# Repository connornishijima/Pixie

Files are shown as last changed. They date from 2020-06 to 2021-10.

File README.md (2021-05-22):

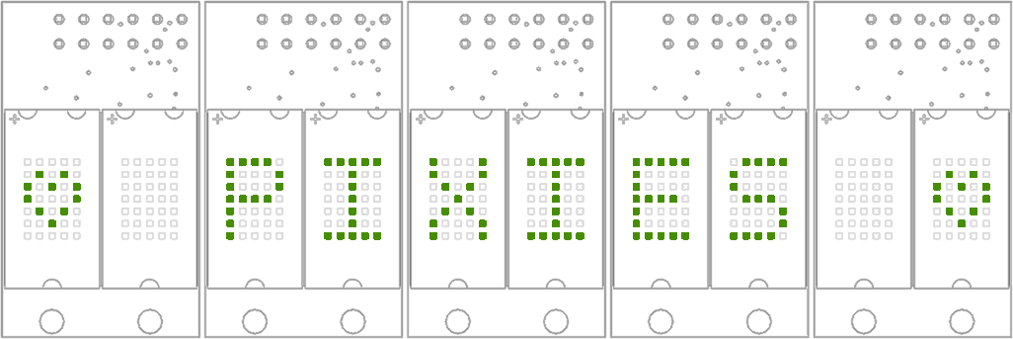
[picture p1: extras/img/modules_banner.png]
Pixie


----------
# Pixie for Arduino

https://www.tindie.com/products/connornishijima/pixie-chainable-dual-57-micro-led-displays/

**Pixies are chainable 5x7 microdot LED matrices great for showing... just about anything you can throw at them!**

- Dual 5x7 LED matrices
- 2.7V to 5.5V supply
- Fast bitmap control
- 7-bit global PWM (128 brightness levels)
- Over-temperature protection
- Resettable from controlling device
- Reprogrammable ATTINY45 microcontroller
- 5.1mm * 7.6mm matrix size (19.92 ppi)
- 20.6mm * 34.7mm package
- M2.5 mouting holes
- Controllable LED current (Pixie Pro)
- Parity bit error detection (Pixie Pro)

PIXIE
*Pixies mounted into a home-made case!*

# New to Pixies?

Thank you for your order! Try our **[Getting Started Guide](https://github.com/connornishijima/Pixie/blob/master/getting_started.md)** to get them wired up!

## Included in this repository:

**[PIXIE WEBSITE](https://connornishijima.github.io/Pixie/) *(Contains all documentation and tools in one spot)***

- Arduino Library Source Code
- Software Documentation
- Hardware Datasheet
- Pixie Icon Generator
- Raspberry Pi Python Driver
- PCB Gerbers

## Software Documentation

Documentation for the Pixie library is available in both the /examples directory for Arduino, and at the site below:

**[Library Documentation & Usage](https://connornishijima.github.io/Pixie/extras/documentation.html)**

We also have a **[Getting Started Guide](https://github.com/connornishijima/Pixie/blob/master/getting_started.md)** to help you get set up for the very first time!

## Hardware Documentation

Pixie has a comprehensive hardware datasheet (including internal firmware documentation and package dimensions for mounting) available here:

**[PIXIE DATASHEET](https://connornishijima.github.io/Pixie/extras/datasheet.html)**

This library also contains a Pixie EAGLE library (In "extras/hardware") for adding Pixies into your own PCB layouts!

----------
# Arduino Library Installation

**With Arduino Library Manager:** ***(Stable - RECOMMENDED)***

1. Open *Sketch > Include Library > Manage Libraries* in the Arduino IDE.
2. Search for "Pixie" by Connor Nishijima, and select the latest version.
3. Click the Install button and Arduino will prepare the library and examples for you!

**Manual Install:** (Hourly Builds)

1. Click "Clone or Download" above to get an "Pixie-master.zip" file.
2. Extract its contents to the libraries folder in your Arduino sketchbook. ("C:/Users/**YOUR_USERNAME**/Documents/Arduino/libraries" on Windows)
3. Rename the folder from "Pixie-master" to "Pixie".

----------
# Build Status


Pixie for Arduino is automatically tested with Travis CI against:
- ATmega328p (Uno)
- ATmega2560 (Mega)
- ATmega32u4 (Leonardo)
- ESP8266
- ESP32

*Currently untested are STM/Cortex or SAMD platforms such as the Teensy 3+ and Arduino MKR.*

Is it marked "Failing"? **No worries!** If you install Pixie using the Arduino Library Manager, you'll be getting the latest stable release. *This GitHub repo is under frequent changes, and some of these changes may be breaking at times.*

----------
# Contributing
Any advice or pull requests are welcome! *(This repository uses **snake_case**, not **camelCase**.)* :)

----------
# License and Credits
**Developed by Connor Nishijima (Copyright 2020)**

I work full-time as a Tindie seller providing income for my family. You are free to make your own Pixies with the infomation provided in this repository, but **please be ethical and *do not sell clones***. If you modify any information from this repository, and have used it to make improvements to my hardware design that you truly think makes your version superior to the original (and thus could compete in sales due to these advantages) then - at the very least - **please attribute** Lixie Labs LLC. if you sell them. (As required by the GPLv3 License below and included in the root of this repository.)

**Released under the [GPLv3 License](http://www.gnu.org/licenses/gpl-3.0.en.html).**

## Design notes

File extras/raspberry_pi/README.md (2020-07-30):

# Pixie Python driver for Raspberry Pi

This is a (mostly) complete port of version 1.2.2 of the Pixie Arduino library to a Python/SPI-based module for Raspberry Pi!

## Notable differences:

Since this is based on Hardware SPI, only the SPI pins can be used to drive the Pixies:

    PIXIE DAT = RPi MOSI
    PIXIE CLK = RPi SCLK
    (No Chip Select or MISO pins used)
    
- **pix.print()** is **pix.printout()** instead to avoid conflict with Python's **print()** function.
- The driver uses SPI at 20,000Hz by default, which can be increased or decreased in **pixie.py**
- **pixie.py** is the Pixie driver, (library equivalent) and must be in the same folder of any scripts importing it.
- This port contains all of the icons included with version 1.2.2, and newer ones may be added by request.
- Custom icons must be defined in brackets when given to a printing function. (Instead of *pix.write(127,127,127,127,127)* you'll need *pix.write(**[**127,127,127,127,127**]**)*
- There is a slightly longer-form way of fetching built-in icons. Instead of pix.write(PIX_HEART) use pix.write(pix.icons["PIX_HEART"])
- pix.flipped() (upside down display), pix.set_pix() and pix.draw_line() are not yet supported.

Other than that, usage is identical to the original library!

### SPI must be enabled using "sudo raspi-config" under "Interfacing Options" (reboot after changing)

#### SPI HOOKUP:
    -----------------+
                     |
     PIX_VCC     X   |
           X     X   |
           X     PIX_GND
           X     X   |
           X     X   |
           X     X   |
           X     X   |
           X     X   |
           X     X   |
     PIX_DAT     X   |
           X     X   |
     PIX_CLK     X   |
           X     X   |
           X     X   |
           X     X   |
           X     X   |
           X     X   |
           X     X   |
           X     X   |
           X     X   |
                     |

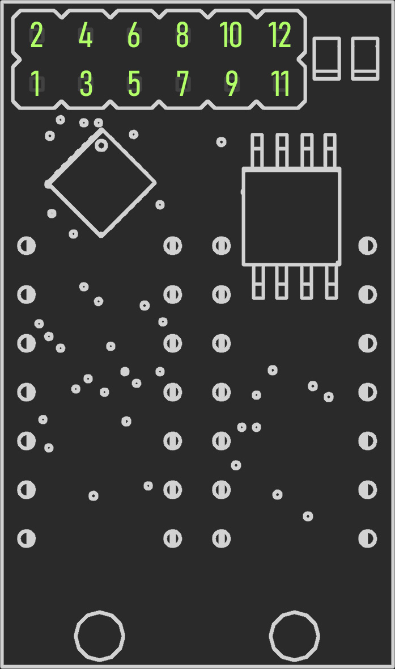
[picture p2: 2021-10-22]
extras/img/pinout.jpg

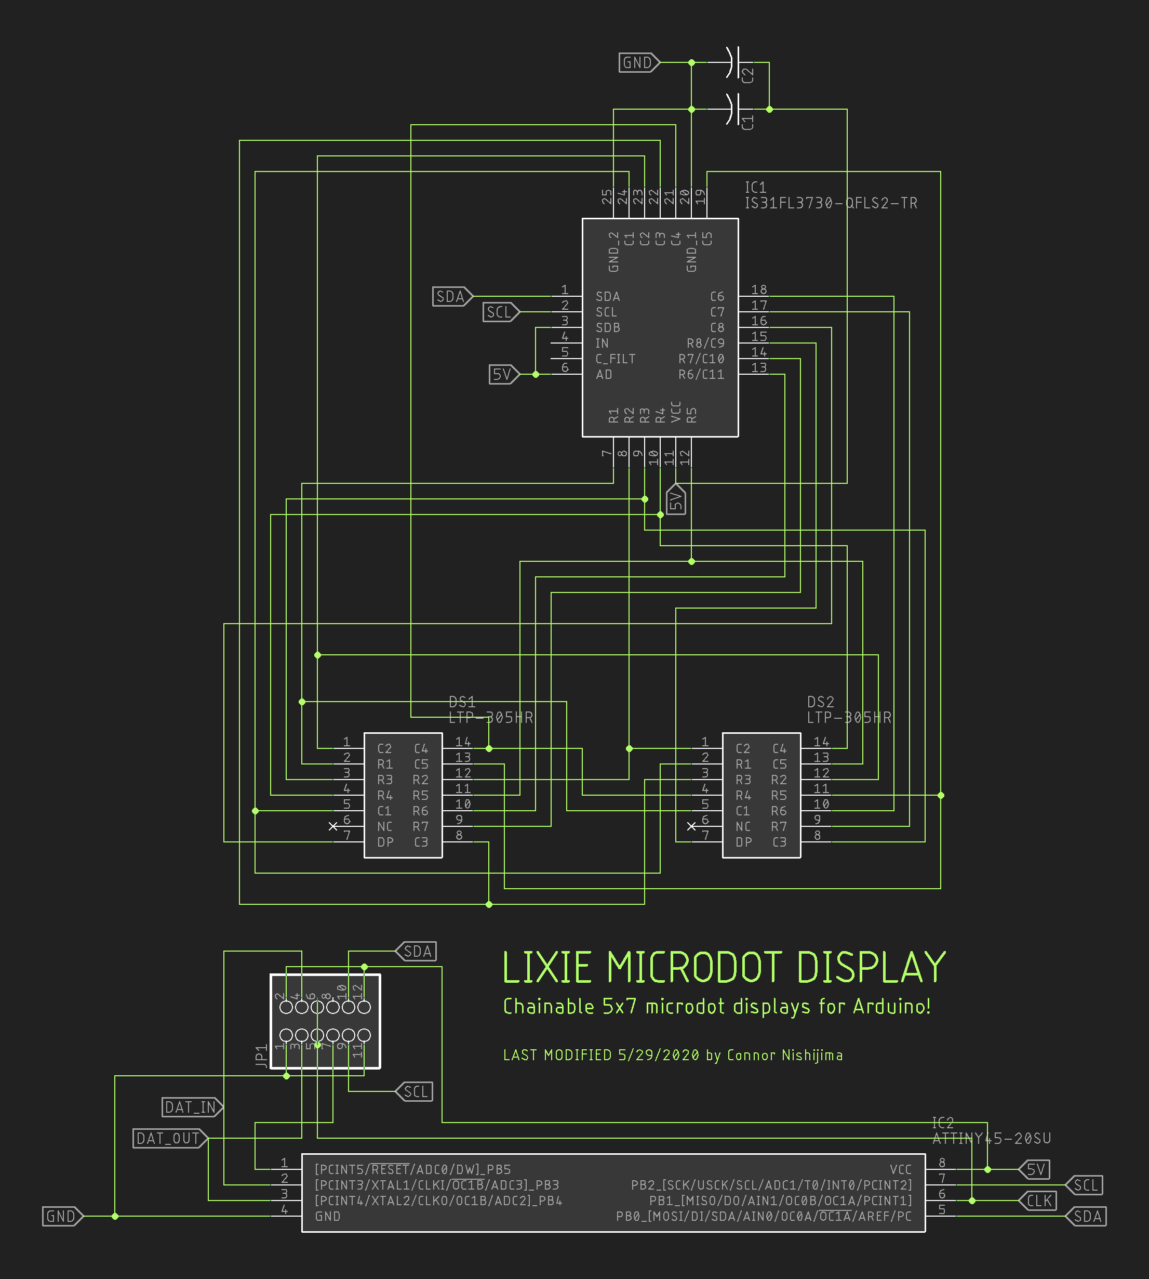
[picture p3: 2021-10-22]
extras/img/schematic.jpg

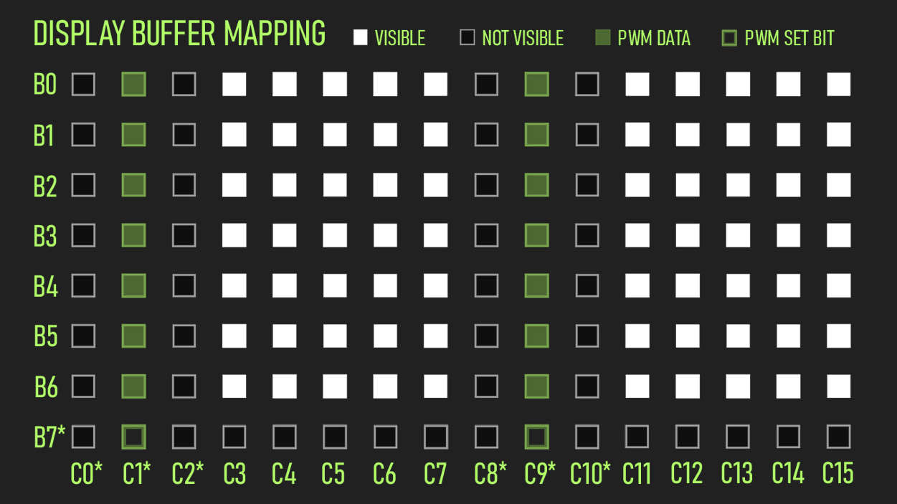
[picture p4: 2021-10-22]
extras/img/buffer_mapping.jpg

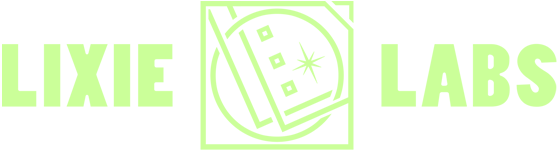
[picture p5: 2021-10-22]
extras/img/vendor.png

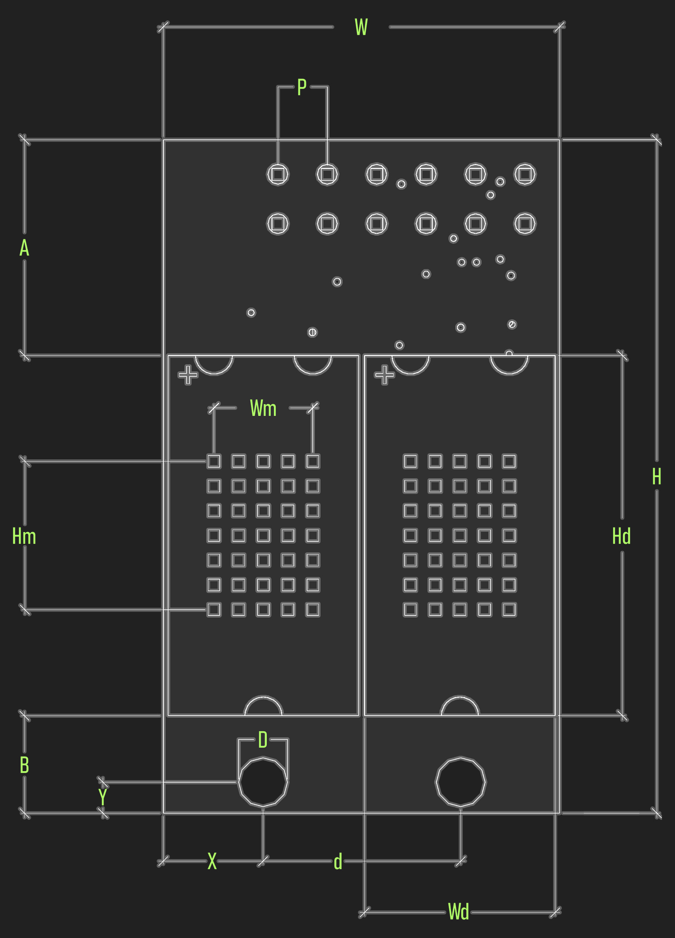
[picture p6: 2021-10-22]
extras/img/dimensions.jpg

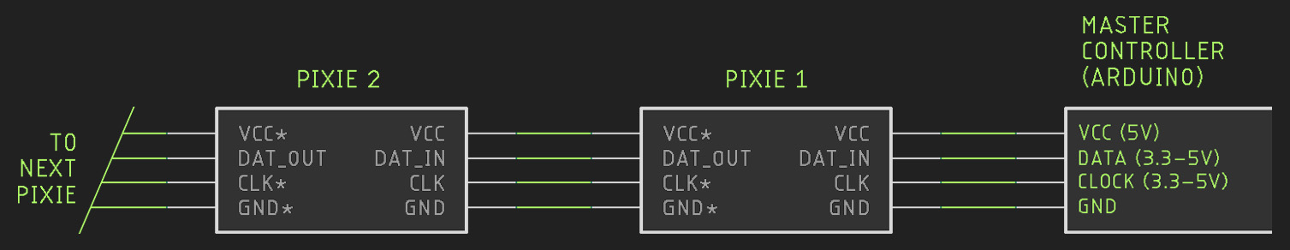
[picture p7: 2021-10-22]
extras/img/application.jpg

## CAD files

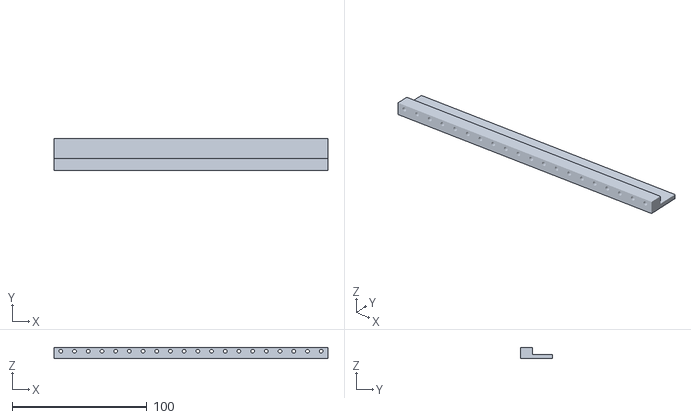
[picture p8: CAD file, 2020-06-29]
extras/3D_printing/10_Pixie_Mount.stl
203.4 x 24.0 x 8.50

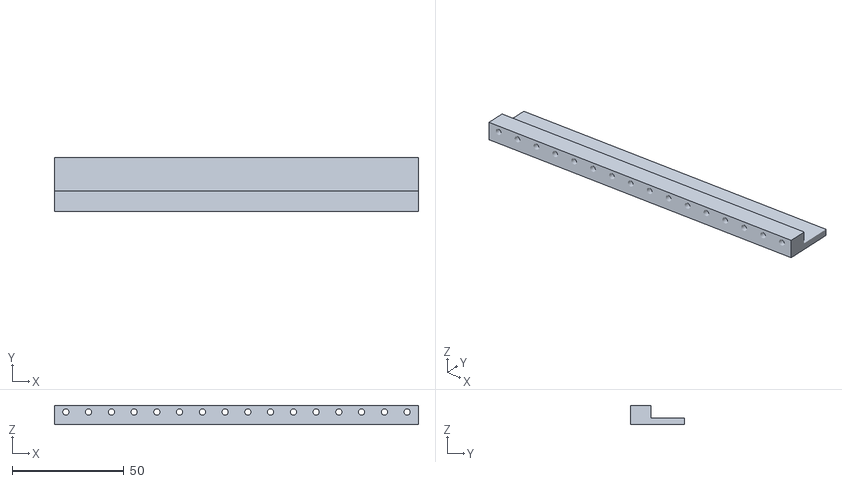
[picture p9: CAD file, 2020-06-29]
extras/3D_printing/8_Pixie_Mount.stl
162.7 x 24.0 x 8.50

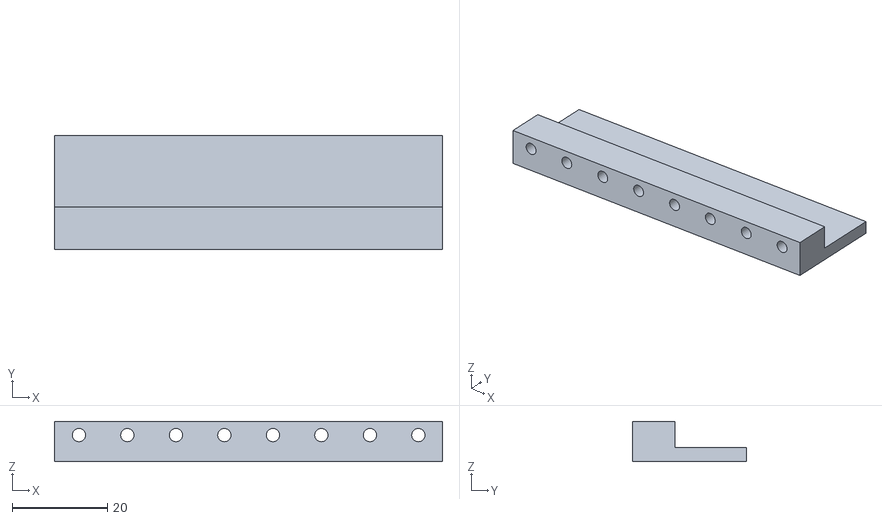
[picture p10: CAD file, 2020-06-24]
extras/3D_printing/4_Pixie_Mount.stl
81.5 x 24.0 x 8.50

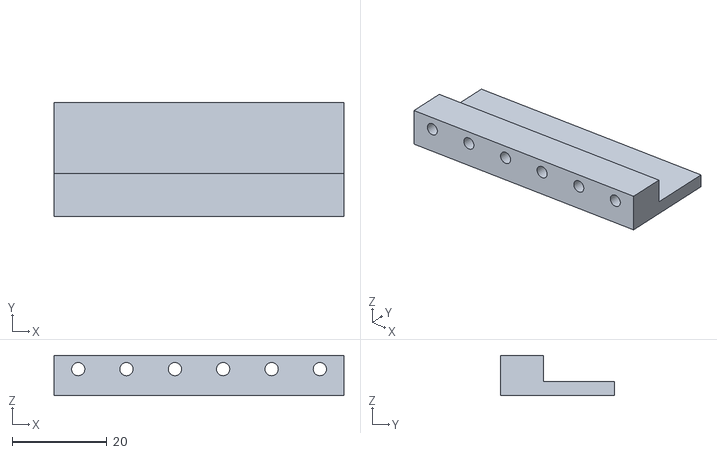
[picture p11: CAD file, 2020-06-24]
extras/3D_printing/3_Pixie_Mount.stl
61.1 x 24.0 x 8.50

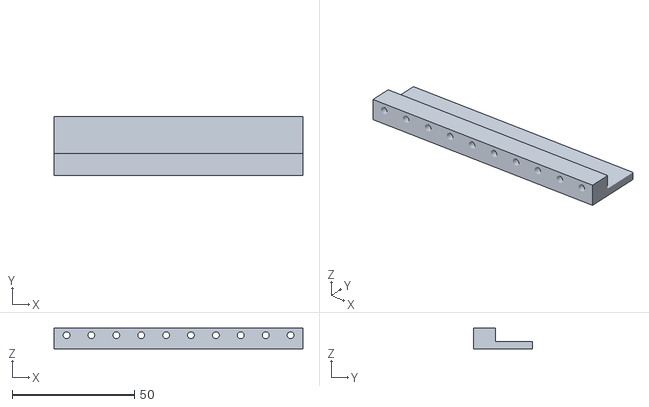
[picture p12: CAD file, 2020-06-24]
extras/3D_printing/5_Pixie_Mount.stl
101.9 x 24.0 x 8.50

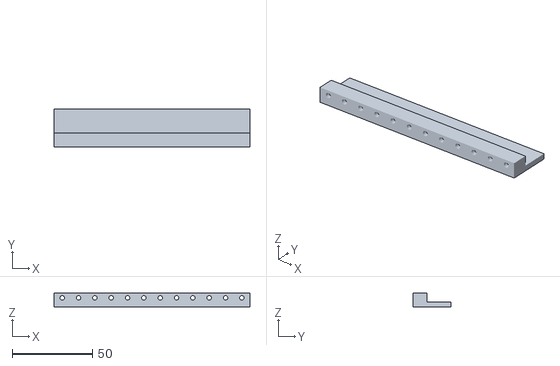
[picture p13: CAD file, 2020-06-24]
extras/3D_printing/6_Pixie_Mount.stl
122.2 x 24.0 x 8.50

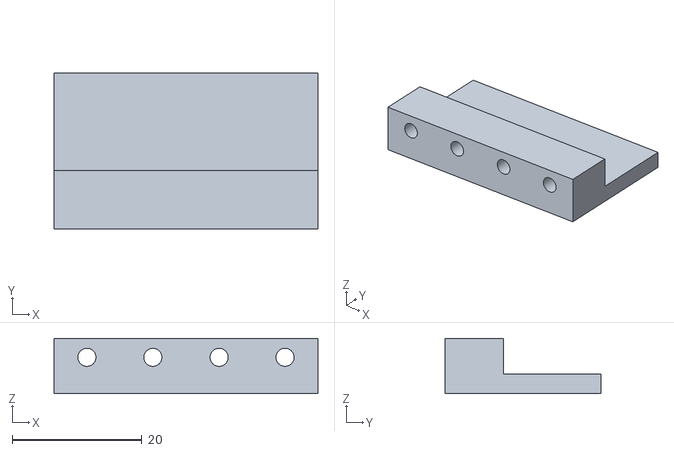
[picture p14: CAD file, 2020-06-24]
extras/3D_printing/2_Pixie_Mount.stl
40.7 x 24.0 x 8.50

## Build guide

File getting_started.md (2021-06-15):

# Getting Started with PIXIE and PIXIE PRO

PIXIE

### *I know you're excited, but we have a few things to cover to make sure you're ready to run Pixie displays!*

# THINGS TO NOTE:

## Microcontroller

Any AVR/Arduino, ESP8266/32/derivative, or SAMD microcontroller can be used to control Pixie displays. There is a Pixie library available for the Arduino IDE:

### Installing the Pixie Library

**With Arduino Library Manager: (RECOMMENDED)**

1. Open *Sketch > Include Library > Manage Libraries* in the Arduino IDE.
2. Search for "Pixie", and select the latest version.
3. Click the Install button and Arduino will prepare the library and examples for you!

**Manual Install:**

1. Click "Clone or Download" above to get an "Pixie-master.zip" file.
2. Extract its contents to the libraries folder in your Arduino sketchbook. ("C:/Users/**YOUR_USERNAME**/Documents/Arduino/libraries" on Windows)
3. Rename the folder from "Pixie-master" to "Pixie".

When finished, an example folder structure for Windows should be:

    C:\Users\[USERNAME]\Documents\Arduino\libraries\Pixie\src\Pixie.cpp

## Powering Pixies

### Pixies are best powered with 5 Volts.

The on-board ATTINY45 is nominally powered with 5 volts DC to maintain the 16MHz clock. If you have a 3V3-logic microcontroller (ESP8266/32), you may or may not have to use [a level shifter](https://www.adafruit.com/product/1787). However, I have successfully run Pixies off of a 3.3V Wemos D1 Mini (ESP8266 controller) without needing a level shifter - even with the ATTINY45 powered by the 5 volt line.

A potential workaround is underpowering the Pixies with a 3.3V power line, but this will only be 66% of the brightness 5V power provides, and *may* destabilize the 16MHz internal oscillator.

#### Full Brightness

If you want to allow for any possible lighting scenario, you'll need to have a power supply that can support ~60mA per Pixie. For a 6-Pixie display flashing every single LED at full-brightness, you would need a power supply capable of 60mA*6 = 360mA. However, most people won't be using Pixies as a lightbar for their off-road truck, so most USB supplies should be just fine for most cases. ;) (Plenty of USB charging blocks can supply this.)

## Wiring

Hookup looks like this:

    MICROCONTROLLER 5V        ---->   PIXIE VCC
    MICROCONTROLLER GND       ---->   PIXIE GND
    MICROCONTROLLER DAT_PIN   ---->   PIXIE DAT_IN
    MICROCONTROLLER CLK_PIN   ---->   PIXIE CLK

Pixies are designed to be daisy-chained, and run from right-to-left. Connecting one display to the next is like this:

CHAIN

*You can use Dupont female-to-female jumpers to connect the displays, or solder directly to the headers. We also have [an EAGLE library available](https://github.com/connornishijima/Pixie/tree/master/extras/hardware) to work Pixie into your own PCBs!*

## PIXIE PINOUT

(From [the hardware datasheet](https://connornishijima.github.io/Pixie/extras/datasheet.html))

PINOUT

If you have 4 or more displays in the chain, I recommend connecting *BOTH* ends of the chain to the 5V/GND lines of the power supply to avoid having dimmer characters at the end of the chain. (Due to the voltage drop across displays) Without doing so, you may notice the displays on the far end of the chain gradually falling into a darker color.

## Writing Arduino code for Pixies

Once you've installed the Pixie library, go ahead and try this example code to make sure everything is working:

    #include "Pixie.h"
    #define NUM_PIXIES  6                          // PCBs, not matrices
    #define CLK_PIN     14                         // Any digital pin
    #define DATA_PIN    12                         // Any digital pin
    Pixie pix(NUM_PIXIES, CLK_PIN, DATA_PIN, PRO); // Set up display buffer
    
    void setup() {
      pix.begin(); // Init display drivers
    }
    
    void loop() {
      pix.clear();
      pix.push( millis()/1000.0, 2 ); // Show floating-point number to two decimal places (hundredths of a second)
      pix.show();
    }

**NOTE: If you're not using a Pixie Pro, you don't need the "PRO" in *Pixie pix();***

Change the **NUM_PIXIES** variable to match the number of Pixie PCBs you have wired up. When uploaded, you should see the seconds since boot (with hundreths) on your Pixies!

## Moving Forward

Once again, if you're using a ***Pixie Pro***, the **Pixie pix(NUM_PIXIES, CLK_PIN, DATA_PIN)** constructor *needs* a "PRO" at the end in all code uploaded, like so:
    
    Pixie pix(NUM_PIXIES, CLK_PIN, DATA_PIN, PRO); <-- HERE

Otherwise, the data will be sent out in a way that Pixie Pro does not recognize, and your image will be distorted!

From here, I suggest trying out the other examples included with the Pixie library, as it covers many of the neat writing and bitmap functions that Pixie is capable of!

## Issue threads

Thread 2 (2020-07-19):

Gerber file incomplete?

eburman, 2020-07-19:
The gerber files provided in "extras" doesn't seem to include any drill files.

connornishijima, 2020-07-29:
Sorry about that! The extras/hardware/Gerbers folder has just been updated with Excellon files!

eburman, 2020-07-30:
Thank you for including the drill files. Unfortunately the drill holes don't all match up. JLCPCB is rejecting the Gerber files because not all of the drill holes match up. So close far.

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

Closed 2020-07-29.

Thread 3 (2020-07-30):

Drill files are a bit off

eburman, 2020-07-30:
Hi, I'm very sorry to be such a drudge but the drill files that you just posted seem to be a bit off. It looks like some of the holes don't match up with where they're supposed to be (some of the vias?). I submitted the Gerber files along with the newly included drill file to JLCPCB but they rejected my order due to the mismatch. They sent me this diagram to show what they thought were errors:
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

connornishijima, 2020-08-04:
Sorry about that! The drill file added was from the beta version, not the final. It has been fixed/reuploaded!

Closed 2020-08-04.

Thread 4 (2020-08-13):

Schematic overview

BenRoe, 2020-08-13:
Hello,
first thank you for this great project.
I am working on a calculator and your pixie seems to be a great way for the digits, but it would be more compact to put everything on the pcb.
Is it possible that you share the schematic of the pixie pcb?

connornishijima, 2020-08-13:
It is in the Pixie Datasheet, page 7: https://connornishijima.github.io/Pixie/extras/datasheet.html?page=7

BenRoe, 2020-08-14:
Thank you.

Closed 2020-08-14.

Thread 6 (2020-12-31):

A simple question

yuhanwen2013, 2020-12-31:
I would like to ask, which two types of capacitors should be selected ，thanks

eburman, 2021-01-01:
Yes. I was wondering the same.

vascobarbosa, 2021-02-28:
same here

vascobarbosa, 2021-03-10:
got them working

1 x 10uf cap

eburman, 2021-03-11:
Thanks vascobarbosa!

yuhanwen2013, 2021-03-14:
cool！

Closed 2021-04-29.

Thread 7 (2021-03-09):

I guess this project is abandoned

vascobarbosa, 2021-03-09:
I ordered the the pcbs from jlpcb
got the hardware from mouser ( led driver and attinys45 )

I am getting some troubles making them work.

I can make a double digit countdown , hardcoded on the attiny

but can't make the firmware work, working on that.
made this thread because there's no answer from
Lixie Labs ( tried github, twitter and tindie store ) so
I guess I'm reverse engineering this , and place my findings here

feel free to contribute please

vascobarbosa, 2021-03-09:
so, this code works, if u want to try the connection between attiny45 and the led driver:

`#include <avr/io.h>

#define I2C_TIMEOUT 10000
#define I2C_FASTMODE 1    // 400kHz
#define I2C_PULLUP 1      // Enable pullups to avoid more passives on board
#define I2C_NOINTERRUPT 1 // No interrupts allowed when sending I2C data
#define SDA_PORT PORTB
#define SCL_PORT PORTB
#define SDA_PIN 0         // PB0
#define SCL_PIN 2         // PB2
#define dd 100

#include <SoftI2CMaster.h> // Include I2C Library
#define I2C_7BITADDR 0x63  // Each Pixie manages it's own display driver at a hard-coded I2C address

const uint8_t CLK_pin     = 1; //PB1
const uint8_t DAT_IN_pin  = 3; //PB3
const uint8_t DAT_OUT_pin = 4; //PB4

byte disp[10];            // Display buffer

byte row[7];
byte rowindex = 0;

byte col[60] = {                     // even digits (2,4,6) have column bit map for each column of 5x7 matrix
    0x00, 0x00, 0x00, 0x00, 0x00,
    0xFF, 0xFF, 0xFF, 0xFF, 0xFF,
    0x3E, 0x51, 0x49, 0x45, 0x3E, // 0        10
    0x00, 0x42, 0x7F, 0x40, 0x00, // 1        11
    0x42, 0x61, 0x51, 0x49, 0x46, // 2        12
    0x21, 0x41, 0x45, 0x4B, 0x31, // 3        13
    0x18, 0x14, 0x12, 0x7F, 0x10, // 4        14
    0x27, 0x45, 0x45, 0x45, 0x39, // 5        15
    0x3C, 0x4A, 0x49, 0x49, 0x30, // 6        16
    0x01, 0x71, 0x09, 0x05, 0x03, // 7        17
    0x36, 0x49, 0x49, 0x49, 0x36, // 8        18
    0x06, 0x49, 0x49, 0x29, 0x1E  // 9        19// #        03
    };

void setup() {
  // put your setup code here, to run once:
  disp[4] = 10;
  delay(10); // Not sure why this works. (Maybe unstable connections when first powered?) Please figure it out.
//  pinMode(CLK_pin,     INPUT);
//  pinMode(DAT_IN_pin,  INPUT);
//  pinMode(DAT_OUT_pin, OUTPUT);

   i2c_init();       // Init bitbang I2C
   init_display();   // Init idsplay driver
   for(int i = 0;i<2;i++){
     Dwrite(1,i);
     delay(dd);
     Dwrite(0,i);
     delay(dd);
     Dwrite(1,i);
     delay(dd);
     Dwrite(0,i);
     delay(dd);
   }
}

int i = 0;

void loop() {
  int f = i/10;
  int r = i%10;
  Dwrite(2+f,0);
  Dwrite(2+r,1);
  delay(dd);
  i++;
  if(i>99) i=0;
}

void update_display(){

}

void init_display() {
  i2c_start_wait((I2C_7BITADDR << 1) | I2C_WRITE); //  write i2c address 0x63
  i2c_write(0xFF);                  // write to reset register
  i2c_write(0x00);                  // write row data - sets dual display mode
  i2c_stop();

  i2c_start_wait((I2C_7BITADDR << 1) | I2C_WRITE); //  write i2c address 0x63
  i2c_write(0x00);                  // write to configuration register
  i2c_write(0x19);                  // write row data - sets dual display mode
  i2c_stop();

  i2c_start_wait((I2C_7BITADDR << 1) | I2C_WRITE); //  write i2c address 0x63
  i2c_write(0x0D);                  // write to LIGHTING EFFECT REGISTER
  i2c_write(0x09);             // sets row current to 40mA
  i2c_stop();

  i2c_start_wait((I2C_7BITADDR << 1) | I2C_WRITE); //  write i2c address 0x63
  i2c_write(0x19);                  // write to PWM REGISTER
  i2c_write(0x80);             // sets pwm to 128 (max)
  i2c_stop();
}

void Dwrite(byte x, int d){
    i2c_start_wait((I2C_7BITADDR << 1) | I2C_WRITE); //  write i2c
    // first digit
    if(d == 0){
      i2c_write(0x0E);                 // write to DIGIT 1
     for (int coly =0; coly<5; coly++ ){
        i2c_write (col[x*5 + coly]);                 //write row data
      }
      }else{
        //second digit
        coltorowconv(x);
         i2c_write(0x01);                 // write to DIGIT 1

      for (int rowx = 0; rowx<7; rowx++ ){
        i2c_write (row[rowx]);
      }
    }
    i2c_stop();

    i2c_start_wait((I2C_7BITADDR << 1) | I2C_WRITE); //  write i2c
    i2c_write(0x0c);
    i2c_write(0xff);
    i2c_stop();

  }

  void coltorowconv(byte digit) {                   // convert column dot matrix to row map

      for (rowindex = 0; rowindex < 7; rowindex++){
            row[rowindex] = 0;
                row[rowindex] =  (bitRead(col[digit * 5 + 0], rowindex) * 1)
                                +(bitRead(col[digit * 5 + 1], rowindex) * 2)
                                +(bitRead(col[digit * 5 + 2], rowindex) * 4)
                                +(bitRead(col[digit * 5 + 3], rowindex) * 8)
                                +(bitRead(col[digit * 5 + 4], rowindex) * 16);

             }    // end rowindex loop
}

`

vascobarbosa, 2021-03-09:
This is a firmware code to test a single pcb ( 2 digits )
with a countdown. To check if the soldering and connection
is working

----------------------------------------------

#include <avr/io.h>

#define I2C_TIMEOUT 10000
#define I2C_FASTMODE 1    // 400kHz
#define I2C_PULLUP 1      // Enable pullups to avoid more passives on board
#define I2C_NOINTERRUPT 1 // No interrupts allowed when sending I2C data
#define SDA_PORT PORTB
#define SCL_PORT PORTB
#define SDA_PIN 0         // PB0
#define SCL_PIN 2         // PB2
#define dd 100

#include <SoftI2CMaster.h> // Include I2C Library
#define I2C_7BITADDR 0x63  // Each Pixie manages it's own display driver at a hard-coded I2C address

const uint8_t CLK_pin     = 1; //PB1
const uint8_t DAT_IN_pin  = 3; //PB3
const uint8_t DAT_OUT_pin = 4; //PB4

byte disp[10];            // Display buffer

byte row[7];
byte rowindex = 0;

byte col[60] = {                     // even digits (2,4,6) have column bit map for each column of 5x7 matrix
    0x00, 0x00, 0x00, 0x00, 0x00,
    0xFF, 0xFF, 0xFF, 0xFF, 0xFF,
    0x3E, 0x51, 0x49, 0x45, 0x3E, // 0        10
    0x00, 0x42, 0x7F, 0x40, 0x00, // 1        11
    0x42, 0x61, 0x51, 0x49, 0x46, // 2        12
    0x21, 0x41, 0x45, 0x4B, 0x31, // 3        13
    0x18, 0x14, 0x12, 0x7F, 0x10, // 4        14
    0x27, 0x45, 0x45, 0x45, 0x39, // 5        15
    0x3C, 0x4A, 0x49, 0x49, 0x30, // 6        16
    0x01, 0x71, 0x09, 0x05, 0x03, // 7        17
    0x36, 0x49, 0x49, 0x49, 0x36, // 8        18
    0x06, 0x49, 0x49, 0x29, 0x1E  // 9        19// #        03
    };

void setup() {
  // put your setup code here, to run once:
  disp[4] = 10;
  delay(10); // Not sure why this works. (Maybe unstable connections when first powered?) Please figure it out.
//  pinMode(CLK_pin,     INPUT);
//  pinMode(DAT_IN_pin,  INPUT);
//  pinMode(DAT_OUT_pin, OUTPUT);

   i2c_init();       // Init bitbang I2C
   init_display();   // Init idsplay driver
   for(int i = 0;i<2;i++){
     Dwrite(1,i);
     delay(dd);
     Dwrite(0,i);
     delay(dd);
     Dwrite(1,i);
     delay(dd);
     Dwrite(0,i);
     delay(dd);
   }
}

int i = 0;

void loop() {
  int f = i/10;
  int r = i%10;
  Dwrite(2+f,0);
  Dwrite(2+r,1);
  delay(dd);
  i++;
  if(i>99) i=0;
}

void update_display(){

}

void init_display() {
  i2c_start_wait((I2C_7BITADDR << 1) | I2C_WRITE); //  write i2c address 0x63
  i2c_write(0xFF);                  // write to reset register
  i2c_write(0x00);                  // write row data - sets dual display mode
  i2c_stop();

  i2c_start_wait((I2C_7BITADDR << 1) | I2C_WRITE); //  write i2c address 0x63
  i2c_write(0x00);                  // write to configuration register
  i2c_write(0x19);                  // write row data - sets dual display mode
  i2c_stop();

  i2c_start_wait((I2C_7BITADDR << 1) | I2C_WRITE); //  write i2c address 0x63
  i2c_write(0x0D);                  // write to LIGHTING EFFECT REGISTER
  i2c_write(0x09);             // sets row current to 40mA
  i2c_stop();

  i2c_start_wait((I2C_7BITADDR << 1) | I2C_WRITE); //  write i2c address 0x63
  i2c_write(0x19);                  // write to PWM REGISTER
  i2c_write(0x80);             // sets pwm to 128 (max)
  i2c_stop();
}

void Dwrite(byte x, int d){
    i2c_start_wait((I2C_7BITADDR << 1) | I2C_WRITE); //  write i2c
    // first digit
    if(d == 0){
      i2c_write(0x0E);                 // write to DIGIT 1
     for (int coly =0; coly<5; coly++ ){
        i2c_write (col[x*5 + coly]);                 //write row data
      }
      }else{
        //second digit
        coltorowconv(x);
         i2c_write(0x01);                 // write to DIGIT 1

      for (int rowx = 0; rowx<7; rowx++ ){
        i2c_write (row[rowx]);
      }
    }
    i2c_stop();

    i2c_start_wait((I2C_7BITADDR << 1) | I2C_WRITE); //  write i2c
    i2c_write(0x0c);
    i2c_write(0xff);
    i2c_stop();

  }

  void coltorowconv(byte digit) {                   // convert column dot matrix to row map

      for (rowindex = 0; rowindex < 7; rowindex++){
            row[rowindex] = 0;
                row[rowindex] =  (bitRead(col[digit * 5 + 0], rowindex) * 1)
                                +(bitRead(col[digit * 5 + 1], rowindex) * 2)
                                +(bitRead(col[digit * 5 + 2], rowindex) * 4)
                                +(bitRead(col[digit * 5 + 3], rowindex) * 8)
                                +(bitRead(col[digit * 5 + 4], rowindex) * 16);

             }    // end rowindex loop
}

eburman, 2021-03-10:
I also have the PCB's and all the parts but I haven't gotten around to building it. I have so many projects and so little time. Maybe I can motivate myself to get it together. It looks like you are way ahead of me.

vascobarbosa, 2021-03-10:
I'm at the point of reading about stuff and found out that arduino as a programmer has diferent
results on windows and on mac as explained on this thread :

https://forum.arduino.cc/index.php?topic=216663.0

so now, I'm scavenging a windows machine to test this theory.

vascobarbosa, 2021-03-10:
ok, Got them working

with attiny85,
1 - 10uf cap

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

eburman, 2021-03-11:
vascobarbosa....Beautiful! Thank you so much for sharing all the detailed information that you discovered!

vascobarbosa, 2021-03-11:
I did made them work in osx also, so I guess the windows doesnt matter at all

Closed 2021-04-29.

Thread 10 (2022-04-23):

Problems with ESP32-C3

tinyledmatrix, 2022-04-23:
might look into this in more detail later, but it it looks like it is not working if a Board with an ESP32-C3 is selected in Adruino IDE.
Seems not to like a bunch of the parts with #ifdef ESP32
But this could be also a problem of the ESP32-C3 Adruino core

tinyledmatrix, 2022-04-23:
okay got it working on ESP32-C3. I did some quick changes in a workaround branch here:
https://github.com/tinyledmatrix/Pixie/tree/ESP32-C3_workarround
This can't get pulled directly, because this branch should not run with old ESPs any more.
Could not find a quick solution to exclude all #if (defined(ESP8266) || defined(ESP32)) sections for ESP32C in Pixie.h, so they are just commented out now.
Pixie.cpp should run on other ESPs, but not tested.

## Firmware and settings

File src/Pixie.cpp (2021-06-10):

/*!
 * @file Pixie.cpp
 *
 * @mainpage Pixie library for Arduino!
 *
 * @section intro_sec Introduction
 *
 * This is the documentation for Lixie Labs' Pixie library for the
 * Arduino platform.  It is designed specifically to work with Pixie displays:
 * https://www.tindie.com/products/connornishijima/pixie-chainable-57-led-displays-for-arduino/
 *
 * @section author Author
 *
 * Written by Connor Nishijima for Lixie Labs 2021.
 *
 * @section license License
 *
 * GPLv3 license, all text here must be included in any redistribution.
 */

#include "Pixie.h"

/**************************************************************************/
/*!
	Used to initialize the Pixie library. Example usage before setup() would be:
	<pre>
	Pixie pix(NUM_PIXIES, CLK_PIN, DATA_PIN, PRO);
	</pre>
	"pix" can be anything you want, as long as it's reflected in the rest of your code. 
	Because each of these functions are wrapped in the Pixie class, you'll use them like this:
	<pre>
	pix.write(num);
	</pre>
*/
/**************************************************************************/
Pixie::Pixie(uint8_t p_count, uint8_t c_pin, uint8_t d_pin, uint8_t p_type){
	CLK_pin = c_pin;
	DAT_pin = d_pin;
	pixie_count = p_count;
	disp_count  = pixie_count*2;
	
	pix_type = p_type;
	
	if(pix_type == PRO){
		display_buffer = new uint8_t[pixie_count*13];
	}
	else{
		display_buffer = new uint8_t[disp_count*8];
	}
}

/**************************************************************************/
/*!
    @brief	Initializes the display buffer and clears the displays (Should be called once in the Arduino setup() function)
	
    @param	speed Can either be omitted/LEGACY_SPEED (39kHz) or FULL_SPEED (67kHz)
*/
/**************************************************************************/
void Pixie::begin(uint8_t speed){
	clk_us = speed;
	pinMode(CLK_pin, OUTPUT);
	pinMode(DAT_pin, OUTPUT);
	reset(); 
	clear();
	if(pix_type == PRO){ // Pro has different hardware requirements!
		clk_us = FULL_SPEED;
		command(PIX_ROW_CURRENT, mA_10);
		command(PIX_LED_FLIP,    true);
	}
	delay(10); // Give Pixies a short time to finish resetting
}

void Pixie::calc_parity(){
	uint16_t byte_count = pixie_count * 13;
	for (uint16_t b = 0; b < byte_count; b++) {
		uint8_t num_1s = 0;
		num_1s += bitRead(display_buffer[b],0);
		num_1s += bitRead(display_buffer[b],1);
		num_1s += bitRead(display_buffer[b],2);
		num_1s += bitRead(display_buffer[b],3);
		num_1s += bitRead(display_buffer[b],4);
		num_1s += bitRead(display_buffer[b],5);
		num_1s += bitRead(display_buffer[b],6);
		bitWrite(display_buffer[b],7, !bitRead(num_1s,0));
	}
}

void Pixie::fill_commands(){
	for(uint8_t i = 0; i < pixie_count; i++){
		write_byte(PIX_WRITE, 0+(13*i)); // command, command data, 7-bit brightness
		write_byte(0,         1+(13*i));
		write_byte(bright,    2+(13*i));
	}
}

/**************************************************************************/
/*!
    @brief	Latches the current display buffer and writes it to the Pixie chain
*/
/**************************************************************************/
void Pixie::show(bool fill_com){
	yield();
	uint16_t total_bytes = disp_count * 8;
	if(pix_type == PRO){
		total_bytes = pixie_count * 13;
		if(fill_com){
			fill_commands();
		}
		calc_parity();
	}
	
	#ifdef SAMD_SERIES
		EPortType port_clk   = g_APinDescription[CLK_pin].ulPort;
		uint32_t pin_clk     = g_APinDescription[CLK_pin].ulPin;
		uint32_t pinMask_clk = (1ul << pin_clk);
		EPortType port_dat   = g_APinDescription[DAT_pin].ulPort;
		uint32_t pin_dat     = g_APinDescription[DAT_pin].ulPin;
		uint32_t pinMask_dat = (1ul << pin_dat);
	#endif
	
	for (uint16_t i = 0; i < total_bytes; i++) {
		for (uint8_t b = 0; b < 8; b++) {
			if(bitRead(display_buffer[i], 7-b)){
				#ifdef ESP8266
					GPOS = (1 << DAT_pin);
				#endif
				
				#ifdef ESP32
					GPIO.out_w1ts = ((uint32_t)1 << DAT_pin);
				#endif
				
				#ifdef SAMD_SERIES
					PORT->Group[port_dat].OUTSET.reg = pinMask_dat;
				#endif
				
				#if !defined(ESP8266) && !defined(ESP32) && !defined(SAMD_SERIES)
					digitalWrite(DAT_pin, HIGH);
				#endif
			}
			else{
				#ifdef ESP8266
					GPOC = (1 << DAT_pin);
				#endif
				
				#ifdef ESP32
					GPIO.out_w1tc = ((uint32_t)1 << DAT_pin);
				#endif
				
				#ifdef SAMD_SERIES
					PORT->Group[port_dat].OUTCLR.reg = pinMask_dat;
				#endif
				
				#if !defined(ESP8266) && !defined(ESP32) && !defined(SAMD_SERIES)
					digitalWrite(DAT_pin, LOW);
				#endif
			}

			#ifdef ESP8266
				GPOS = (1 << CLK_pin);
			#endif
			#ifdef ESP32
				GPIO.out_w1ts = ((uint32_t)1 << CLK_pin);
			#endif
			#ifdef SAMD_SERIES
				PORT->Group[port_clk].OUTSET.reg = pinMask_clk;
			#endif
			#if !defined(ESP8266) && !defined(ESP32) && !defined(SAMD_SERIES)
				digitalWrite(CLK_pin, HIGH);
			#endif
			
			delayMicroseconds(clk_us);
			
			#ifdef ESP8266
				GPOC = (1 << CLK_pin);
				ESP.wdtFeed();
			#endif
			#ifdef ESP32
				GPIO.out_w1tc = ((uint32_t)1 << CLK_pin);
			#endif
			#ifdef SAMD_SERIES
				PORT->Group[port_clk].OUTCLR.reg = pinMask_clk;
			#endif
			#if !defined(ESP8266) && !defined(ESP32) && !defined(SAMD_SERIES)
				digitalWrite(CLK_pin, LOW);
			#endif
			
			delayMicroseconds(clk_us);
		}
	}
	
	#ifdef ESP8266
		GPOC = (1 << DAT_pin);
	#endif
	#ifdef ESP32
		GPIO.out_w1tc = ((uint32_t)1 << DAT_pin);
	#endif
	#ifdef SAMD_SERIES
		PORT->Group[port_dat].OUTCLR.reg = pinMask_dat;
	#endif
	
	#if !defined(ESP8266) && !defined(ESP32) && !defined(SAMD_SERIES)
		digitalWrite(DAT_pin, LOW);
	#endif
	
	if(pix_type == PRO){
		yield();
		delayMicroseconds(1750);		
	}
	else{
		delay(7);
	}
	
	yield();
}

/**************************************************************************/
/*!
    @brief	Sets the brightness of the Pixie chain using a 7-bit range (0-127)
	
    @param	b 7-bit brightness level to set.
*/
/**************************************************************************/
void Pixie::brightness(uint8_t b){
	if(pix_type == PRO){
		bright = b;
		fill_commands();
		show();
	}
	else{
		bitWrite(b,7,1);
		bright = b;
		for(uint8_t i = 0; i < disp_count; i++){
			write_brightness(b, i);
		}
		show();
	}
}

/**************************************************************************/
/*!
    @brief	Clears the display buffer
*/
/**************************************************************************/
void Pixie::clear(){
	for (uint16_t d = 0; d < disp_count*8; d++) {
		display_buffer[d] = 0;
	}
	cursor_pos = 0;
}
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

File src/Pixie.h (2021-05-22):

/*!
 * @file Pixie.h
 *
 * Library for controlling Pixie Displays!
 * Created by Connor Nishijima, June 8th 2020.
 * Released under the GPLv3 license, all text here must be included in any redistribution.
 */

#ifndef pixie_h
#define pixie_h
#include "Arduino.h"

// FONT SELECTION ---------
// - There are two built-in fonts to choose from.
//   Uncomment a single option below to choose.
//   (font_alt has fancy numerals)

	#include "font.h"
//	#include "font_alt.h"
// ------------------------

#define LEGACY 0  // Original Pixies with 128 bit buffer
#define PRO    1  // Pixie Pro with 104-bit buffer

#define LEGACY_SPEED 12  // ~39kHz bitrate
#define FULL_SPEED   7   // ~67kHz bitrate (Firmware 1.1.0+)

#define PIX_WRITE       0
#define PIX_LED_FLIP    1
#define PIX_ROW_CURRENT 2
#define PIX_RESET 	3

#define mA_5   8
#define mA_10  9
#define mA_35 14
#define mA_40  0
#define mA_45  1

/**************************************************************************/
/*! 
    @brief	Pixie class, containing all of the coolest functions!
*/
/**************************************************************************/
class Pixie{
  public:
    Pixie(uint8_t d_count, uint8_t c_pin, uint8_t d_pin, uint8_t p_type = LEGACY);
        void begin(uint8_t speed = LEGACY_SPEED); // Defaults to LEGACY_SPEED
	void show(bool fill_com = true);
	void brightness(uint8_t b);
	void write_brightness(uint8_t bright, uint8_t pos);
	void clear();
	
	void command(uint8_t com, uint8_t data = 0);
	
	void write_char(char input, uint8_t pos = 0);
	void write(char     input, uint8_t pos = 0);
	void write(char*    input, uint8_t pos = 0);
	void write(int16_t  input, uint8_t pos = 0);
	void write(uint16_t input, uint8_t pos = 0);
	void write(int32_t  input, uint8_t pos = 0);
	void write(uint32_t input, uint8_t pos = 0);
	#if defined(ESP8266) || defined(ESP32)
		void write(long unsigned int input, uint8_t pos = 0); // same as uint32_t, but Arduino is stupid
	#endif
	void write(float  input, uint8_t places = 2, uint8_t pos = 0);
	void write(double input, uint8_t places = 2, uint8_t pos = 0);
	void write(uint8_t* icon, uint8_t pos = 0);
	void write(uint8_t byte1, uint8_t byte2, uint8_t byte3, uint8_t byte4, uint8_t byte5, uint8_t pos = 0);	
	void write_byte(uint8_t col, uint16_t pos);
	
	void print_char(char input);
	void print(char     input);
	void print(char*    input);
	void print(int16_t  input);
	void print(uint16_t input);
	void print(int32_t  input);
	void print(uint32_t input);
	#if defined(ESP8266) || defined(ESP32)
		void print(long unsigned int input); // same as uint32_t, but Arduino is stupid
	#endif
	void print(float  input, uint8_t places = 2);
	void print(double input, uint8_t places = 2);
	void print(uint8_t* icon);
	void print(uint8_t byte1, uint8_t byte2, uint8_t byte3, uint8_t byte4, uint8_t byte5);
	
	void set_cursor(uint8_t pos);

	void push_char(char chr);	
	void push_byte(uint8_t col);
	void push(char     input);
	void push(char*    input);
	void push(int16_t  input);
	void push(uint16_t input);
	void push(int32_t  input);
	void push(uint32_t input);
	#if defined(ESP8266) || defined(ESP32)
		void push(long unsigned int input); // same as uint32_t, but Arduino is stupid
	#endif
	void push(float  input, uint8_t places = 2);
	void push(double input, uint8_t places = 2);
	void push(uint8_t* icon);
	void push(uint8_t byte1, uint8_t byte2, uint8_t byte3, uint8_t byte4, uint8_t byte5);
	
	void shift_char(char chr);	
	void shift_byte(uint8_t col);
	void shift(char     input);
	void shift(char*    input);
	void shift(int16_t  input);
	void shift(uint16_t input);
	void shift(int32_t  input);
	void shift(uint32_t input);
	#if defined(ESP8266) || defined(ESP32)
		void shift(long unsigned int input); // same as uint32_t, but Arduino is stupid
	#endif
	void shift(float  input, uint8_t places = 2);
	void shift(double input, uint8_t places = 2);
	void shift(uint8_t* icon);
	void shift(uint8_t byte1, uint8_t byte2, uint8_t byte3, uint8_t byte4, uint8_t byte5);
	
	void draw_line(int16_t x1, int16_t y1, int16_t x2, int16_t y2);
	
	uint8_t get_length(uint32_t input);
	#if defined(ESP8266) || defined(ESP32)
		uint8_t get_length(long unsigned int input);
	#endif
	uint8_t get_length(int32_t input);
	uint8_t get_length(float input, uint8_t places);
		
	void scroll_message(char* input, uint16_t wait_ms = 100, bool instant = false);
	void scroll(char* input);
	void smooth_scroll(char* input);
		
	void set_pix(uint16_t x, uint16_t y, uint8_t state);
	
	void dump_buffer();
	
	void reset();
	
  private:
	void calc_parity();
	void fill_commands();
	uint8_t clk_us = LEGACY_SPEED;

	uint8_t pix_type = LEGACY;
	uint8_t pixie_count  = 0;
	uint8_t disp_count   = 0;
	
	uint8_t bright = 255;
	uint8_t CLK_pin;
	uint8_t DAT_pin;
	uint8_t *display_buffer;
	uint8_t cursor_pos = 0;
	bool push_flip = false;
	
	bool display_flipped = false;
};

#endif

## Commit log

2020-06-14 Added Typical Application Circuit
2020-06-15 Fixed layout of Display Buffer Map in datasheet
    [Pixie.cpp, Pixie.h]
2020-06-20 Added basic Raspberry Pi support!
2020-06-23 Added EAGLE Footprint/Library
2020-06-24 Added 3D-printable mounts
    [2_Pixie_Mount.stl, 3_Pixie_Mount.stl, 4_Pixie_Mount.stl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]
2020-06-29 Clarified reset register usage
    [Pixie_Firmware_100.ino]
2020-06-29 Datasheet revision to correct dimension error
    [10_Pixie_Mount.stl, 8_Pixie_Mount.stl]
2020-07-01 Added print() functionality, updated examples and keywords.txt
2020-07-29 Added Pixie Drill Files
    [copper_bottom.gbr, copper_top.gbr, drill_1_16.xln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]
2020-07-30 Converted Raspberry Pi driver to SPI
2020-07-30 Pixie library port to RasPi driver!
2020-07-30 Raspberry Pi port documentation
2020-08-04 Fixed Gerber upload (Drill revision issue)
    [copper_bottom.gbr, copper_top.gbr, drill_1_16.xln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]
2020-08-09 Fix for ESP32 core not having...tone()? Really?
    [NTP_CLOCK.ino]
2020-08-09 Test against mega328, mega2560, mega32u4, ESP8266, ESP32
2021-10-22 [ImgBot] Optimize images
    *Total -- 2,355.14kb -> 1,804.56kb (23.38%)
    /extras/img/modules_banner.png -- 59.28kb -> 33.52kb (43.45%)
    /extras/img/vendor.png -- 16.46kb -> 9.88kb (39.98%)
    /extras/img/dimensions_2.jpg -- 225.67kb -> 137.97kb (38.86%)
    /extras/img/dimensions.jpg -- 370.96kb -> 262.90kb (29.13%)
    /extras/img/schematic.jpg -- 652.13kb -> 474.65kb (27.22%)
    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
